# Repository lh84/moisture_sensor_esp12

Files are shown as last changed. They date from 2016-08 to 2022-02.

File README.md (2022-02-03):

REV 1.0

# Moisture Sensor with an ESP8266 12F (Wifi/Wlan)

This project is still work in progress!

This sensor is intended to measure the soil moisture of plants and to send them by WIFI to a server for data evaluation. An ESP8266 module is used for the sender to send data over the air. A capacitive measuring method is used as a sensor to get moisture values. The basic framework of the sensor is based on the [Gies-O-Mat von Fred Ram]<sup>[1]</sup>.

## power source

A 18650 battery is to be used as power source, as this can have high capacities. A long life per battery can be guaranteed. It is assumed that the sensor can operate for up to 3 months at half-hour measurement - This must still be proven!

## Board-Layout

Layout was made with Eagle 7.7<sup>[2]</sup>.

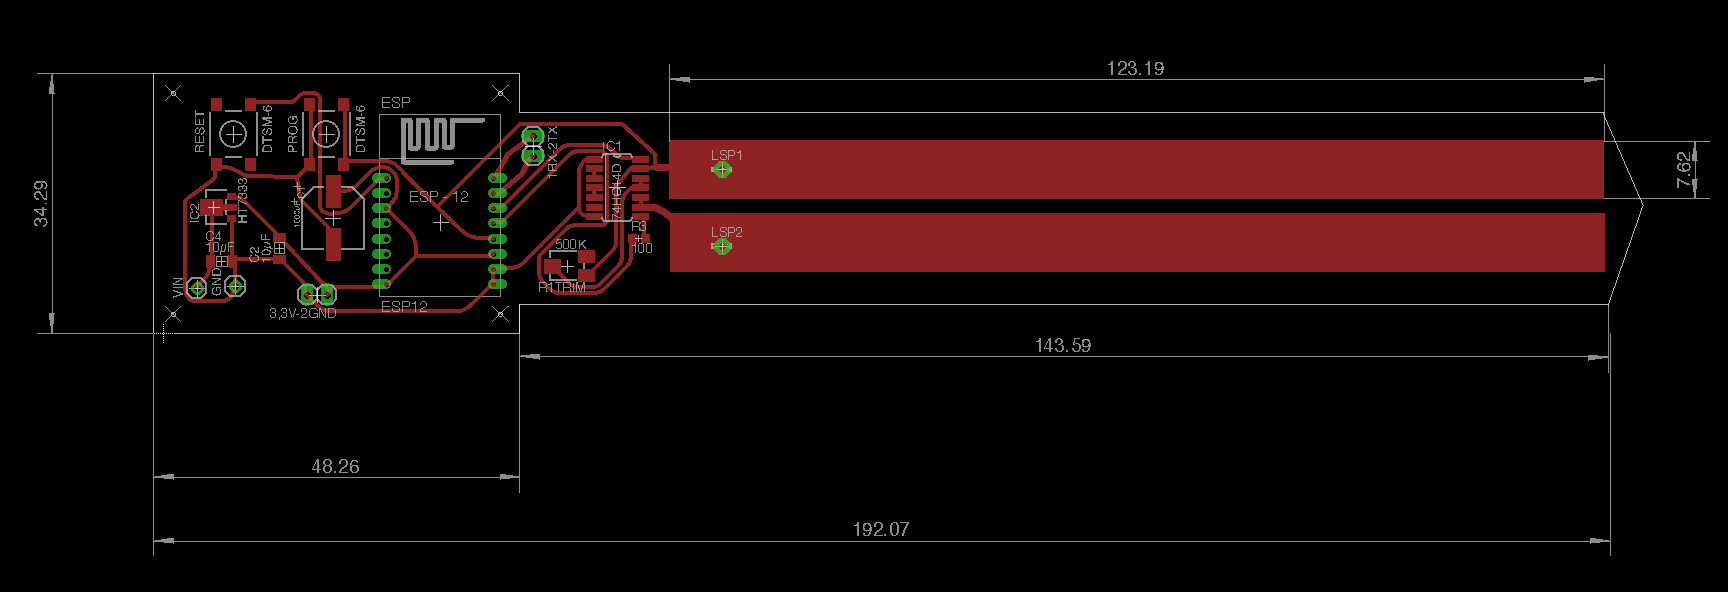
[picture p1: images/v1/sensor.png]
Board


First try to model a case for the board in 3d
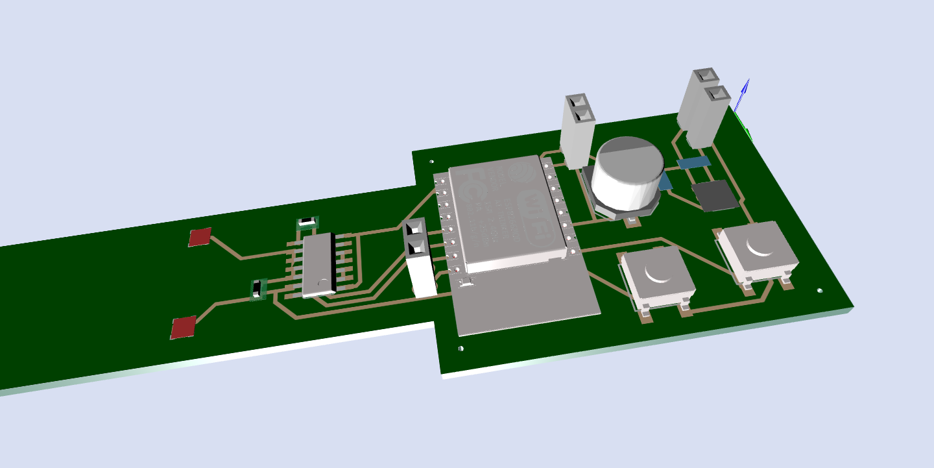
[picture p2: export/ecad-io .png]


GPIO5 is now used to control Vin in smitt trigger to use less power when sensor is not measuring.

## Part-List

| Qty | Value | Device | Package | Parts | Description | Price per pc | Order-Link | 
|-----|---|---|---|---|---|---|---|
| 2 | PINHD-1X2 | 1X02 | 1RX-2TX | 3,3V-2GND | PIN HEADER | 0,28 € (0,71 € / 10pc) | https://www.reichelt.de/Buchsenleisten/MPE-115-1-010/3/index.html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 | 
| 1 | 100Ω |  R-EU_R0603 | R0603 | R3 | RESISTOR, European symbol | 0,02 € | https://www.reichelt.de/SMD-0603-von-0-bis-910-Ohm/RND-0603-1-100/3/index.html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 | 
| 1 | 1000µF | CP-SV-E/F | SV-E/F | C1 |  Big POLARIZED CAP | 0,32 €  | https://www.reichelt.de/Elkos-SMD-Low-ESR-105-C/VF-1000-6-3-P-F/3/index.html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 | 
| 2 | 10µF | C1206 | 1206 | C2, C4 | Small SMD Cap | 0,07 € | https://www.reichelt.de/Vielschicht-SMD-G1206/X7R-G1206-10-16/3/index.html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 | 
| 1 | 500KΩ | R-TRIMM3374 | R-TRIMM3374 | R1TRIM | Trimm resistor til 500KΩ | 0,67 €  | https://www.reichelt.de/Miniaturtrimmer/23B-500K/3/index.html?ACTION=3&GROUPID=3131&ARTICLE=146090&OFFSET=16& | 
| 1 | 74HC14D 74HC14D | SO14 | IC1 | Hex schmitt trigger | INVERTER | 0,18 €  | https://www.reichelt.de/ICs-74HC-SMD/SMD-HC-14/3/index.html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 | 
| 2 | DTSM-6  DTSM-6  | DTSM-6 | PROG, RESET | | Push button | 0,24 €  | https://www.reichelt.de/Kurzhubtaster/TASTER-9314/3/index.html?ACTION=3&GROUPID=7587&ARTICLE=44510&OFFSET=500& | 
| 1 | ESP12 | ESP12 | ESP12 | ESP | ESP8266 Wifi module 12 | 2,54 €  | https://www.aliexpress.com/item/1-pcs-x-ESP-12F-ESP8266-ESP-12F-Remote-Serial-Port-WIFI-Transceiver-Wireless-Module-UNO/32581210212.html | 
| 1 | HT7333 | HT7333 | SOT-89 | IC2 | Step Down Module (Ultra low current 4µA) | 0,12 € (1,18€ / 10pc) | https://www.aliexpress.com/item/10PCS-HT7333-A-SOT89-HT7333-1-SOT-89-HT7333A-1-7333-1-SMD-7333A-1-new/32531141419.html | 
| 2 | LSP11 | LSP11 | LSP11 | LSP1, LSP2 | SOLDER PAD | no costs | | 
| 1 | Platine | EPCU | | | Size 200X100, one side copper | 0,58 € (1,75 €) | https://www.reichelt.de/Platinenzuschnitte/EPCU-200X100/3/index.html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 |
| 1 | Accu 18650 | | | | e.g. LG ICR18650S3 - 2200mAh, 3,6 - 3,7V Lithium Ionen Akku | 3,95 € | https://www.akkuteile.de/lg-icr18650s3-2200mah/a-100629 |
| 1 |  18650 Holder | | | | | 0,44 € | https://de.aliexpress.com/item/Hot-With-Wire-Lead-Plastic-18650-Battery-3-7V-Clip-Holder-Storage-Box-Case-Cheap-Sale/32458234409.html |
||
|**Sum**||||||**10,00€ + shipping + work**||

Reichelt Order List: https://www.reichelt.de/my/1310317

see also file https://github.com/lh84/moisture_sensor_esp12/blob/master/bom.txt

## Software

As software you can use the source code von Zentris<sup>[3]</sup>. Version 2.2 works pretty good with some small changes.

## Testing

First test at 20/01/17 was pretty good with this new designed board.

## Prototypes

I made a first prototype of the new design with etching at home. Looks und works pretty good for the first test.

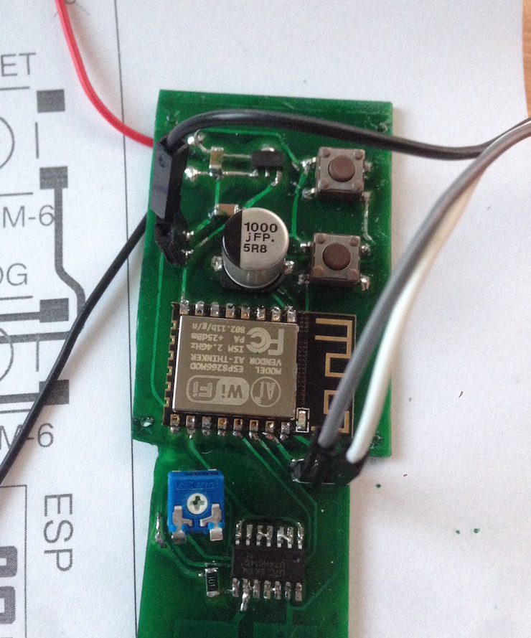
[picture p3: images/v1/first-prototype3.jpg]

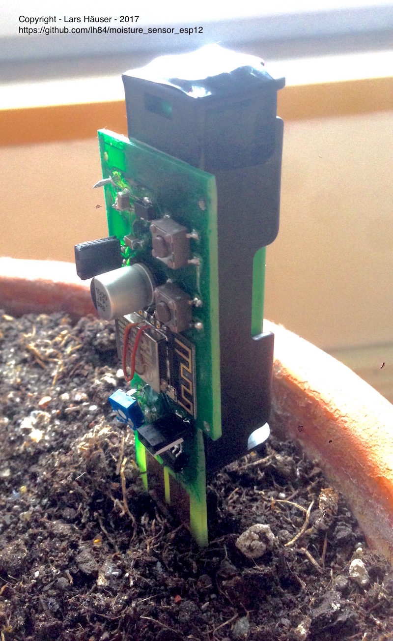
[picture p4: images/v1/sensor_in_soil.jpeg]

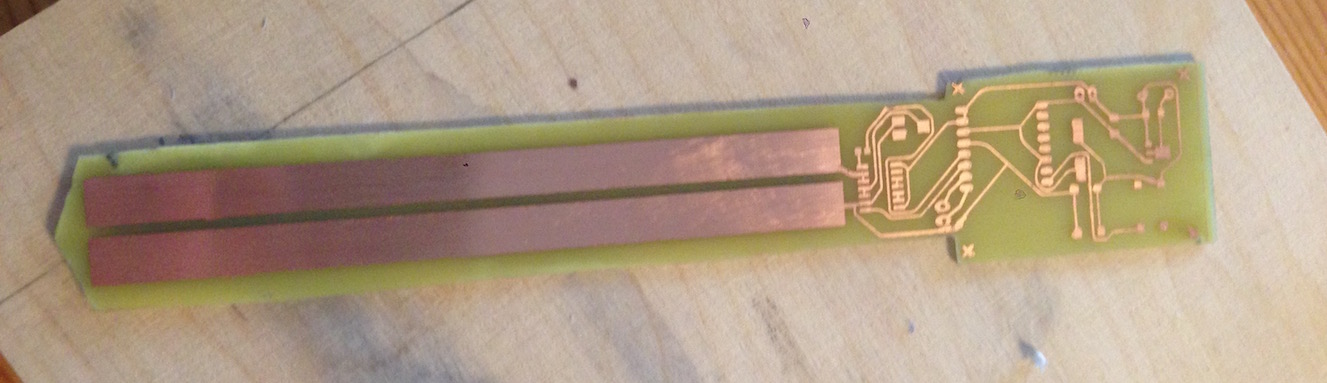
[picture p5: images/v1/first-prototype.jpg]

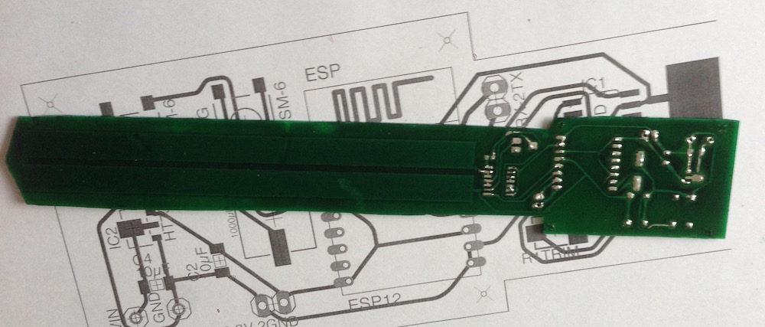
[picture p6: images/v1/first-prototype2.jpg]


## First tests with prototype

You can see the live data from my first sensor prototype monitored in thingspeak:
https://thingspeak.com/channels/210863/charts/1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

## Contribute?

You have an idea how this sensor can be designed better? Then write me or send a request.

## TODO
- [ ] Model case for board (fusion 360)
- [ ] Add battery monitoring with voltage devider (http://www.esp8266-projects.com/2015/03/internal-adc-esp8266.html)

## Done
- [x] build first prototype
- [x] check hardware (first prototype)
- [x] check runtime with 18650 battry - see comments in https://github.com/lh84/moisture_sensor_esp12/issues/3
- [x] test hardware in outdoor environment

[1]: https://www.mikrocontroller.net/topic/335407
[2]: https://cadsoft.io/de/
[3]: https://github.com/Zentris/erdfeuchtemessung

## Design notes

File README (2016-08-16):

# Bodenfeuchte Sensor mit einem ESP12 (Wifi/Wlan)

Dieser Sensor ist noch in Bearbeitung. Es soll dazu dienen, die Bodenfeuchte von Pflanzen zu messen und per WLan an einen Server zur Datenauswertung zu senden. Für das Sender per Wlan wird ein ESP8266 Modul verwendet. Als Sensor kommt eine kapazitive Messmethode zum Einsatz. Das  Grundgerüst des Sensors basiert auf den [Gies-O-Mat von Fred Ram][1].

## Stromquelle

ALs Stromquelle soll ein 18650 AKku dienen, da dieser über hohe Kapazitäten verfügen kann. So kann eine lange Lebensdauer pro Batterie gewährleistet werden. Es wird davon ausgegangen, dass der Sensor bei halbstündiger Messung bis zu 3 Monate arbeiten kann. (Dies muss noch bewiesen werden)

## bisherige Part-Liste

Part       Value          Device     Package  Library        Sheet

1RX-2TX                   PINHD-1X2  1X02     pinhead        1
13,3V-2GND                PINHD-1X2  1X02     pinhead        1
C1         1000µF         CP-SV-E/F  SV-E/F   cap-master     1
C2         10µF           C1206      1206     capsmd         1
C4         10µF           C1206      1206     capsmd         1
ESP                       ESP12      ESP12    esp8266modules 1
GND                       PINHD-1X1  1X01     pinhead        1
IC1        74HC14D        74HC14D    SO14     74xx-eu        1
IC2        HT7333         HT7333     SOT-89   holtek2        1
PAD1                      2,54/1,0   2,54/1,0 wirepad        1
PAD2                      2,54/1,0   2,54/1,0 wirepad        1
PROG       DTSM-6         DTSM-6     DTSM-6   switch-tact    1
R2         ca 100k        R-EU_R0603 R0603    rcl            1
R3         100            R-EU_R0603 R0603    rcl            1
RESET      DTSM-6         DTSM-6     DTSM-6   switch-tact    1
VIN                       PINHD-1X1  1X01     pinhead        1

## Contribute?

Du möchtest mithelfen, dass Design oder die Software zu verbessern? Dann schreib mir oder sende ein Request.

[1]: https://www.mikrocontroller.net/topic/335407

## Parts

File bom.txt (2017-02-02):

Qty	Value	Device	Package	Parts	Description	Price	Link
2	PINHD-1X2	1X02	1RX-2TX	3,3V-2GND	PIN HEADER	0,71€/10pc	https://www.reichelt.de/Buchsenleisten/MPE-115-1-010/3/index.html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
1	100	 R-EU_R0603	R0603	R3	RESISTOR, European symbol	0,02€/pc	https://www.reichelt.de/SMD-0603-von-0-bis-910-Ohm/RND-0603-1-100/3/index.html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
1	1000µF	CP-SV-E/F	SV-E/F	C1	 Big POLARIZED CAP	0,32€/pc	https://www.reichelt.de/Elkos-SMD-Low-ESR-105-C/VF-1000-6-3-P-F/3/index.html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
2	10µF	C1206	1206	C2, C4	Small SMD Cap	0,07€/pc	https://www.reichelt.de/Vielschicht-SMD-G1206/X7R-G1206-10-16/3/index.html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
1	500K	R-TRIMM3374	R-TRIMM3374	R1TRIM	Trimm resistor til 500KΩ	0,67€/pc	https://www.reichelt.de/Miniaturtrimmer/23B-500K/3/index.html?ACTION=3&GROUPID=3131&ARTICLE=146090&OFFSET=16&
1	74HC14D 74HC14D	SO14	IC1	Hex schmitt trigger	INVERTER	0,18€/pc	https://www.reichelt.de/ICs-74HC-SMD/SMD-HC-14/3/index.html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
2	DTSM-6  DTSM-6	DTSM-6	PROG, RESET		Push button 	0,24€/pc	https://www.reichelt.de/Kurzhubtaster/TASTER-9314/3/index.html?ACTION=3&GROUPID=7587&ARTICLE=44510&OFFSET=500&
1	ESP12	ESP12	ESP12	ESP	ESP8266 Wifi module 12	2,54€/pc	https://www.aliexpress.com/item/1-pcs-x-ESP-12F-ESP8266-ESP-12F-Remote-Serial-Port-WIFI-Transceiver-Wireless-Module-UNO/32581210212.html
1	HT7333	HT7333	SOT-89	IC2	Step Down Module (Ultra low current 4µA)	1,18€/10pc	https://www.aliexpress.com/item/10PCS-HT7333-A-SOT89-HT7333-1-SOT-89-HT7333A-1-7333-1-SMD-7333A-1-new/32531141419.html
2	LSP11 	LSP11	LSP11	LSP1, LSP2	SOLDER PAD	no costs

| Qty | Value | Device | Package | Parts | Description | Price per pc | Order-Link | 
|-----|---|---|---|---|---|---|---|
| 2 | PINHD-1X2 | 1X02 | 1RX-2TX | 3,3V-2GND | PIN HEADER | 0,28 € (0,71 € / 10pc) | https://www.reichelt.de/Buchsenleisten/MPE-115-1-010/3/index.html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 | 
| 1 | 100Ω |  R-EU_R0603 | R0603 | R3 | RESISTOR, European symbol | 0,02 € | https://www.reichelt.de/SMD-0603-von-0-bis-910-Ohm/RND-0603-1-100/3/index.html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 | 
| 1 | 1000µF | CP-SV-E/F | SV-E/F | C1 |  Big POLARIZED CAP | 0,32 €  | https://www.reichelt.de/Elkos-SMD-Low-ESR-105-C/VF-1000-6-3-P-F/3/index.html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 | 
| 2 | 10µF | C1206 | 1206 | C2, C4 | Small SMD Cap | 0,07 € | https://www.reichelt.de/Vielschicht-SMD-G1206/X7R-G1206-10-16/3/index.html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 | 
| 1 | 500KΩ | R-TRIMM3374 | R-TRIMM3374 | R1TRIM | Trimm resistor til 500KΩ | 0,67 €  | https://www.reichelt.de/Miniaturtrimmer/23B-500K/3/index.html?ACTION=3&GROUPID=3131&ARTICLE=146090&OFFSET=16& | 
| 1 | 74HC14D 74HC14D | SO14 | IC1 | Hex schmitt trigger | INVERTER | 0,18 €  | https://www.reichelt.de/ICs-74HC-SMD/SMD-HC-14/3/index.html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 | 
| 2 | DTSM-6  DTSM-6  | DTSM-6 | PROG, RESET | | Push button | 0,24 €  | https://www.reichelt.de/Kurzhubtaster/TASTER-9314/3/index.html?ACTION=3&GROUPID=7587&ARTICLE=44510&OFFSET=500& | 
| 1 | ESP12 | ESP12 | ESP12 | ESP | ESP8266 Wifi module 12 | 2,54 €  | https://www.aliexpress.com/item/1-pcs-x-ESP-12F-ESP8266-ESP-12F-Remote-Serial-Port-WIFI-Transceiver-Wireless-Module-UNO/32581210212.html | 
| 1 | HT7333 | HT7333 | SOT-89 | IC2 | Step Down Module (Ultra low current 4µA) | 0,12 € (1,18€ / 10pc) | https://www.aliexpress.com/item/10PCS-HT7333-A-SOT89-HT7333-1-SOT-89-HT7333A-1-7333-1-SMD-7333A-1-new/32531141419.html | 
| 2 | LSP11 | LSP11 | LSP11 | LSP1, LSP2 | SOLDER PAD | no costs | | 
| 1 | Platine | EPCU | | | Size 200X100, one side copper | 0,58 € (1,75 €) | https://www.reichelt.de/Platinenzuschnitte/EPCU-200X100/3/index.html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 |
| 1 | Accu 18650 | | | | e.g. LG ICR18650S3 - 2200mAh, 3,6 - 3,7V Lithium Ionen Akku | 3,95 € | https://www.akkuteile.de/lg-icr18650s3-2200mah/a-100629 |
| 1 |  18650 Holder | | | | | 0,44 € | https://de.aliexpress.com/item/Hot-With-Wire-Lead-Plastic-18650-Battery-3-7V-Clip-Holder-Storage-Box-Case-Cheap-Sale/32458234409.html |
||
|**Sum**||||||**10,00€ + shipping + work**||

Reichelt Order List:
https://www.reichelt.de/my/1310317

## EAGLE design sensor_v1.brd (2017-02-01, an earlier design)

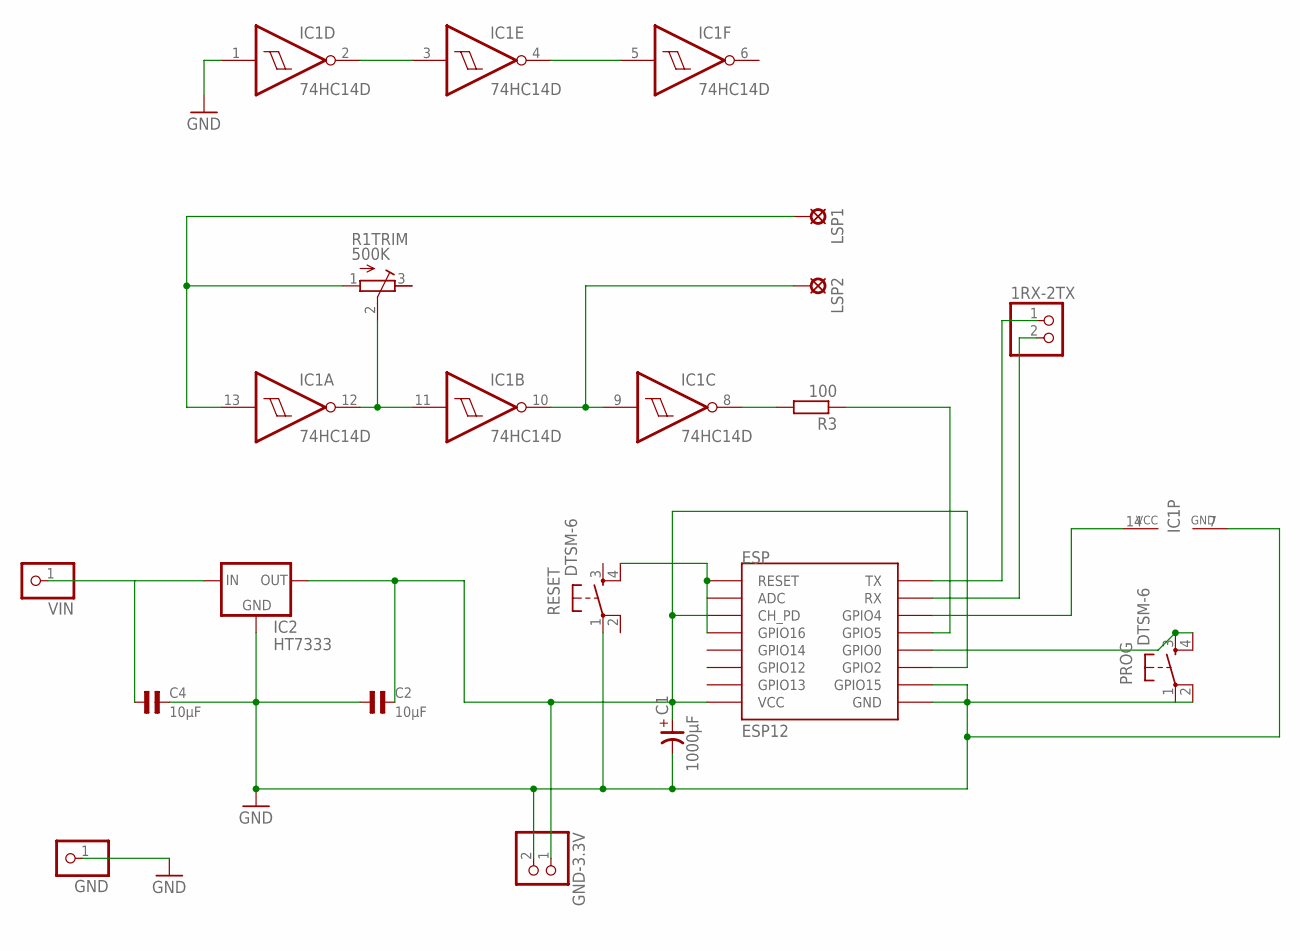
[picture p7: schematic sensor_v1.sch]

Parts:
1RX-2TX: PINHD-1X2; 1X02
C1: 1000µF; SV-E/F
C2, C4: 10µF; 1206
ESP: ESP12
GND: PINHD-1X1; 1X01
GND-3.3V: PINHD-1X2; 1X02
IC1: 74HC14D; SO14
IC2: HT7333; SOT-89
LSP1, LSP2: LSP11
PROG: DTSM-6
R1TRIM: 500K; RTRIM3374
R3: 100; R0603
RESET: DTSM-6
VIN: PINHD-1X1; 1X01

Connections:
3.3V: C1.+, C2.2, ESP.CH_PD, ESP.GPIO2, ESP.VCC, GND-3.3V.1, IC2.1 (OUT)
BIS6VVCC: C4.1, IC2.3 (IN), IC2.4 (IN), VIN.1
GND: C1.-, C2.1, C4.2, ESP.GND, ESP.GPIO15, GND.1, GND-3.3V.2, IC1.1 (I), IC1.7 (GND), IC2.2 (GND), PROG.1, PROG.2, RESET.1
unnamed: 1RX-2TX.1, ESP.TX
unnamed: 1RX-2TX.2, ESP.RX
unnamed: ESP.GPIO4, IC1.14 (VCC)
unnamed: ESP.GPIO16, ESP.RESET, RESET.4
unnamed: IC1.2 (O), IC1.3 (I)
unnamed: IC1.4 (O), IC1.5 (I)
unnamed: IC1.9 (I), IC1.10 (O), LSP2.MP
unnamed: IC1.11 (I), IC1.12 (O), R1TRIM.2 (S)
unnamed: ESP.GPIO0, IC1.13 (I), LSP1.MP, PROG.3, PROG.4, R1TRIM.1 (A)
unnamed: IC1.8 (O), R3.2
unnamed: ESP.GPIO5, R3.1

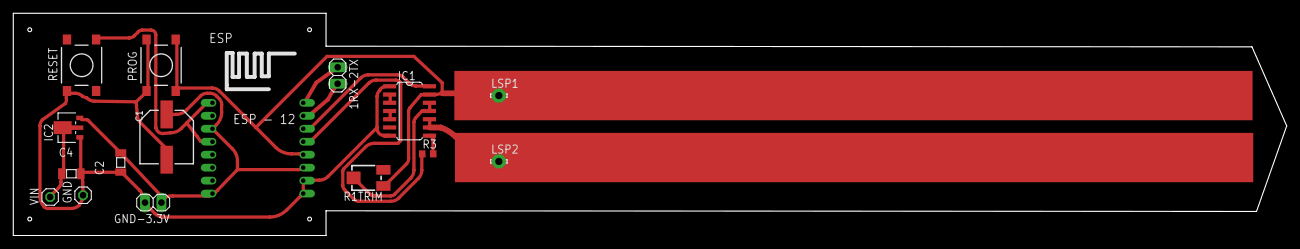
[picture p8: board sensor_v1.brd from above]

Board: 2 copper layers, 196.5 x 34.3 mm, 16 parts (0 on the bottom side), 14 nets.

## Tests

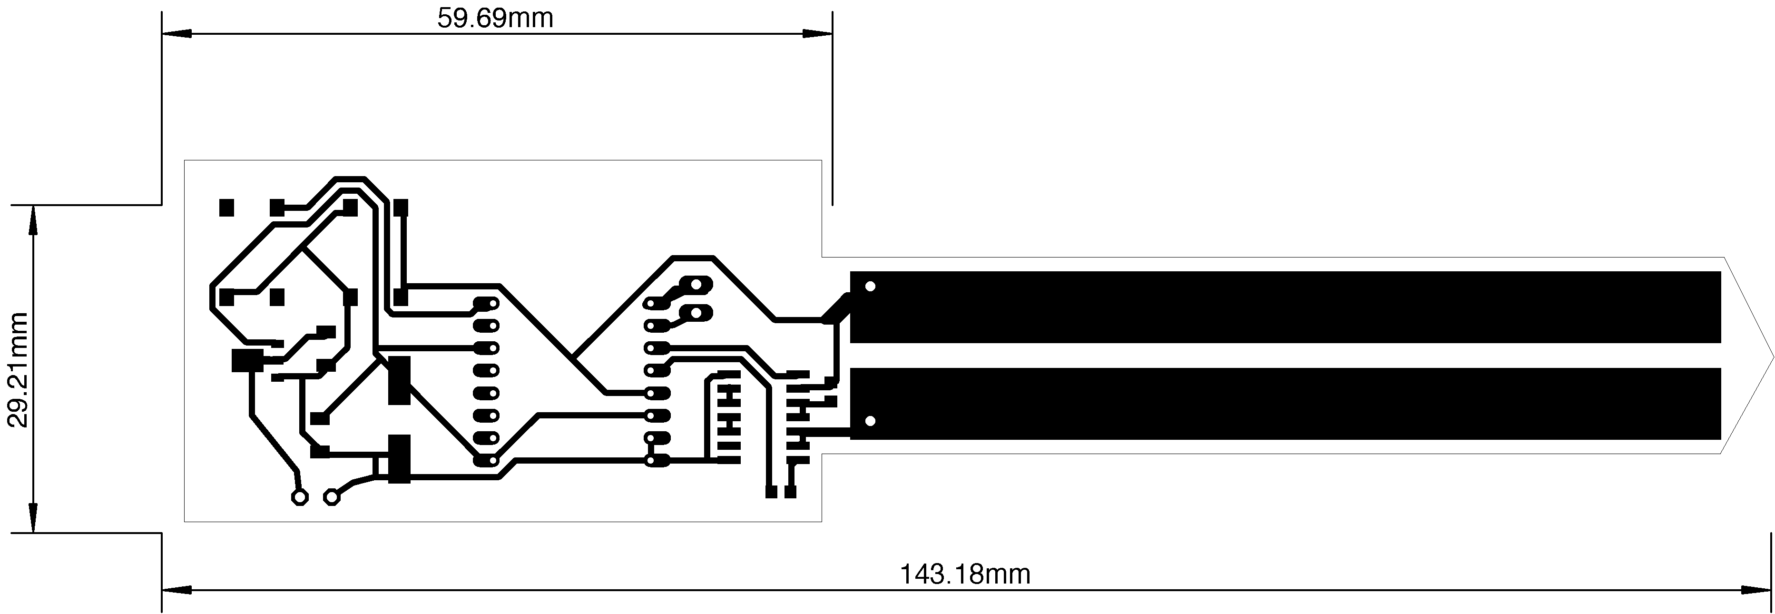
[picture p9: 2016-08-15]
export/test.png

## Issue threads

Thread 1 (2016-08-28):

Vorschlag: Anpassung der Software für Tiefschlaf

Zentris, 2016-08-28:
Die ursprüngliche Software ist ausgelegt für den ESP8266-01. Dieser hat aufgrund seiner nur eingeschränkten GPIO-Anzahl nicht die Möglichkeit, auf ein retriggern aus dem Tiefschlaf (timergesteuert) zu erwachen.

Durch den Einsatz des ESP8266-12(E) könnte die Möglichkeit des Tiefschlafs des ESP genutzt werden, um den Stromverbrauch drastisch zu reduzieren und die Laufzeit/Akkuladung zu erhöhen.

lh84, 2017-01-22:
Hi @Zentris Danke für den Hinweis. Ich habe nun mein Board soweit fertig und habe deine SOftware V2.2. genutzt. Sie funktioniert echt prima. Danke für deine Arbeit. Ich werde bald mit meinem Board ein paar richtige Tests in Erde machen... Mal sehen wie es läuft und wie lange die 18650 durch hält.

Closed 2017-01-22.

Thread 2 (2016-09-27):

Tested?

theopensourcerer, 2016-09-27:
This is almost identical to something I have wanted to design for ages now. Thanks for sharing :-)

I have an ESP-12F in my polytunnel recording Temperature and Humidity over MQTT and my job for this winter was to build some moisture sensors too.

Can I ask if you have _tested_ the circuit design and PCB layout yet? I am very tempted to order a few boards from Oshpark and try it out.

lh84, 2016-10-30:
Hi theopensourcerer,
the design is not tested yet. I want to build and test the project over the next months during winter time :) I will update the project here as soon as I get new results. But if you want to contribute pease feel free to test everything and please let me know if you find a better solution.

theopensourcerer, 2016-10-30:
I bought a couple of the simple Giesomat Sensor kits and have built one but I don't think it is working. Maybe my soldering was rubbish :-(

I have three designs of sensor to test but ultimately I want the same thing as you. A single board with the ESP and the sensor electronics. I may order a board or two of your design from Oshpark and see how they get on.

I grow chillies :-D What is your plant of choice?

theopensourcerer, 2016-12-11:
Hi again,

I bought 74HC14 for my breadboard to test the circuit design before committing to building a PCB...

What frequency is the output of the Schmitt trigger on your board? On a quick test on a breadboard I am seeing around 200KHz. I can't imagine an ESP8266 being able to (reliably) measure at that speed as there are no h/w timers available?

lh84, 2016-12-12:
Hi, I didn't have enough time at the moment and work on it. Can you read German? As mentioned here --> http://www.mikrocontroller.net/topic/369582 you can increase the resistor to decrease the frequency. Let me know if it is working

theopensourcerer, 2016-12-12:
Interesting - so a 1M R seems to drop the frequency down to ~50Khz or so. I'm still not sure if this kind of speed is easily read by the ESP. And I also wonder if slowing it will reduce the resolution of the sensor at all?

The other sensor I like (a stripped down version of the CHIRP) has a tiny Attiny441 AVR on the sensor stick which runs code to convert frequency to i2c. I am beginning to think this might be a better solution...

https://github.com/Miceuz/i2c-moisture-sensor

theopensourcerer, 2016-12-12:
Alternatively, there is a sensor from a Chinese company called DFROBOT which uses a similar technique to the Giessomat but it has a very simple circuit which looks like it converts the frequency to an analogue voltage. I have one of these sensors too and it works. (I do not understand _how_ it works but it does work).

At the bottom of this page are links - one is to the schematic for the sensor... It is very simple :-)

https://www.dfrobot.com/wiki/index.php/Capacitive_Soil_Moisture_Sensor_SKU:SEN0193

lh84, 2016-12-19:
hi @theopensourcerer did you test it with changing just the resistor?

theopensourcerer, 2016-12-20:
Sort of ;-) I don't have an oscilloscope - am using piscope on my Raspberry pi and I am not really sure if it made any difference in all honesty. I am going to (hopefully if I get some time) try a few things over the Christmas break.

Like a simple halfwave rectifier, which is what the DFROBOT sensor uses as a digital to analogue converter. And also there is some code here https://github.com/Zentris/erdfeuchtemessung, also in German, which I do not understand and can't get to compile but it does seem to work, from what I can gather using Google Translate, in reading fairly high frequencies directly.

lh84, 2016-12-20:
The author of https://github.com/Zentris/erdfeuchtemessung told me this morning (here http://www.mikrocontroller.net/topic/335407?goto=4834987#4834987), when you change the resistor to 200K the frequ changes to around 120kHZ which the ESP can handle.

Above 150kHZ the ESP crashes.

I will update the schematic at weekend and will replace the R2 with a trimmer potentiometer till 500K.

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

theopensourcerer, 2016-12-20:
Cool - that is encouraging.

FYI: I did manage to do one test today which was to pass the frequency output of the schmitt trigger through a very simple halfwave rectifier (one diode, one small capacitor and one resistor). I then fed this into a MCP3202 A/D converter just so I could read the result on my Raspberry Pi (over i2c). That also seemed to work as an alternative method. The ultimate idea being you pass the frequency through the rectifier and straight into the ADC pin of the ESP8266.

lh84, 2017-01-22:
Hi @theopensourcerer now I tested the board. And it works really well. I change some details and added a trim resistor (500KΩ) to adjust the output frequency to around 150 KHz (max). See the new images in [readme](https://github.com/lh84/moisture_sensor_esp12/blob/master/README.md).

Closed 2017-01-22.

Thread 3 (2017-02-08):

Battery measurement

theopensourcerer, 2017-02-08:
I noticed your comment about measuring the battery voltage...

I am simply using the internal measurement of the ESP (this means the ADC doesn't work but you get a decent idea of the power anyway.

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

This screenshot above was a test of an environment monitor that slept for 10 seconds, then it ran for about 5 seconds to send data back to my server. I wanted to see how long an 18650 (~2500mAh) would last. (About 36 hours).

But the interesting data is the relatively slow decay of voltage as seen by the ESP. I am using an MCP1700-3302E LDO regulator: http://uk.rs-online.com/web/p/low-dropout-voltage-regulators/6989044/

Zentris, 2017-02-09:
I think, this LDO is very tightly dimensioned:
I have measured peaks up to 350mA while the WLAN transmitter is active...
Futuremore i think, the wakup/sleep ratio (5s/10s+5s = 0.3 ) is to big:

A medium current of 200mA assumed:
200mA * 0.3 = 66mA => 2500mAh / 66mA = (around) 37h working time... :-)

Suggestion: Try to increase the sleep time (if possible) to 300sec (!).

theopensourcerer, 2017-02-09:
I have :-). That was my first test just to check reliability.

The same circuit board is now running on a 10 minute sleep cycle - which is how it will be when it goes into my Polytunnel. This run is on a different battery and I have a suspicion that some of mine are less good than others.

But the point was that voltage measurement doesn't need to use an external divider and the ADC port.

https://github.com/theopensourcerer/esp8266_envmonitor/blob/master/code/src/main.cpp#L46

The graph clearly shows how the voltage degrades. The good thing was that the ESP wasstill able to transmit when the supply VCC was only 2.63v.

theopensourcerer, 2017-02-24:
My Environment test is still running since the 6th February and the VCC measurement of the ESP has not dropped below 3.20v yet, although I suspect it is about to. It has been "bouncing" between 3.21v and 3.20v almost since the very start of the test, but now it is spending more time at 3.20 and less at 3.21v.

theopensourcerer, 2017-03-09:
Just to follow up on this, my test on a 10 minute sleep cycle ran for approximately 28.7 days. Which is OK for my needs.

lh84, 2017-06-02:
@zentris when you place a big cap of 1000uF between vcc and gnd of the ESP you can minimize the peaks very well. See the video of Andreas Spieß. He explains it very well. https://youtu.be/6SdyImetbp8

Closed 2025-10-02.

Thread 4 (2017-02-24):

License?

theopensourcerer, 2017-02-24:
Hi again,

I wanted to know what license you want to use for your schematic and PCB design? The reason I ask, is I have re-designed your work in Kicad (my preferred schematic and board design tool) and want to publish in my own repository on Github. I will, obviously, attribute you as the originator but I need to know the license. If you have not chosen a license yet, I have started using the "Solderpad License" for schematics and PCB designs as it seemed rather appropriate (and I know the author):

http://solderpad.org/licenses/SHL-0.51/

It is quite a liberal license based on Apache 2.0.

theopensourcerer, 2017-03-06:
Would you mind if I use a Creative Commons - Attribution-NonCommercial-ShareAlike? The reason I suggest this is that I am using another idea for the actual probe layout (seems to be very high capacitance BTW - my probe on the bench was recording frequencies in the range of 15kHz - 80kHz with a couple of 100kOhms) and this author used a Creative Commons:

https://github.com/acolomitchi/cap-soil-moisture-v2

lh84, 2017-06-02:
Hi,
sorry that I didn't answer. I didn't get any notifications from github. I don't know which license is the best.

But I would prefer when we bundle all the know How at this repo. What do you think?

lh84, 2022-02-03:
https://github.com/lh84/moisture_sensor_esp12/blob/master/LICENSE

lh84, 2022-02-03:
https://github.com/lh84/moisture_sensor_esp12/blob/master/LICENSE

Closed 2022-02-03.

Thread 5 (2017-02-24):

Question about the potentiometer

theopensourcerer, 2017-02-24:
I can see two possible issues with using a potentiometer to adjust the frequency:

1. How to reliably calibrate several sensors so they all read the same
2. How to prevent "drift" as the potentiometer wears/moves over time

I am interested if you considered anything like this?

lh84, 2017-06-02:
Hi, I just used the poti to determine the best resistor value. I think it would be the best to use a fixed resistor after prototyping

Closed 2025-10-02.

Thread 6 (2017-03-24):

Progress :-)

theopensourcerer, 2017-03-24:
See attached images. I've designed a new board based on your ideas, and others, using Kicad. I got the PCBs back from Seedstudio* the other day. I tested the sensor plate and schmitt trigger before soldering the rest of the components and I'll see if I can get some code running on it over the weekend.

The oscillator frequency varies a _lot_ when I hold the probe in my hand... If I get the variable resistor set right, the frequency changes from ~65kHz down to about 15kHz.

Once I've got some code working I will be able to to some proper tests and measurements.

The sensor plate is symmetrical on both sides of the PCB - I believe this increases the capacitance of the plate considerably.

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

PS: Seedstudio were very cheap. I had 10 boards made, and shipped, for $25.

ctripodi, 2017-05-20:
Hello, I really appreciate you project. Do you have news about the current status? What about the source code? Is there some recommendation?

lh84, 2017-06-02:
Hi Alan, it looks really good! The price sound pretty good. Have you done some tests already? How stable is the frequency over weeks?

lh84, 2017-06-02:
Hi ctripodi,
As software you can use the code from zentris https://github.com/Zentris/erdfeuchtemessung it worked pretty good for my case.
Unfortunately my last sensor broke after 6 weeks running and I had no time to overhaul the sensor. So much to do at work :( I hope I will get back soon to this project

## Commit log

2016-08-15 initial commit of moisture sensor
    [bodenfeuchte.brd, bodenfeuchte.sch]
2016-10-30 - updated board to egale 7.7 - first try with ecad.io - first exported 3d model of board
    [bodenfeuchte.brd]
2017-01-22 - new version of board - added trim resistor (500KΩ) to adjust cap. frequency (works like a charm) - better routing - made first real prototype board (self etching) - board works great with Zentris s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
2017-01-22 - added new image of board
2017-02-01 reorder structure for more versions
    [sensor_v1.brd, sensor_v1.sch, sensor_v2.brd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]
2017-02-01 new image sensor_in_soil.jpeg
2017-02-02 added excel for bom
    [bom.xlsx]
